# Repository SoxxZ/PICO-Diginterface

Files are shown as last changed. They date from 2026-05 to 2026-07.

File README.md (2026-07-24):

# PICO-Diginterface

An RP2040-based digital interface for amateur radio. Enumerates as a UAC2 sound card and CDC virtual COM port, providing microphone input, PDM speaker output, dual PTT channels, and CAT control passthrough over a single USB connection.

Inspired by [AIOC](https://github.com/skuep/AIOC).

---

## Hardware

The PCB implements full galvanic isolation between the host interface and the radio to eliminate ground loops and RF interference, using PC817 optocouplers and 1:1 600 ohms isolation transformers.

### Pinout

| GPIO | Function | Direction | Notes |
|---|---|---|---|
| 4 | UART1 TX | Output | Inverted, 4800 baud |
| 5 | UART1 RX | Input | Inverted, pull-up enabled |
| 12 | PTT Status LED | Output | Active high; asserted when any PTT channel is active |
| 17 | PDM Data Out | Output (PIO) | PDM bitstream at 1.536 MHz |
| 22 | PTT Channel 1  | Output | Active high |
| 24 | PTT Channel 2  | Output | Active high |
| 25 | Board LED | Output | Blinks USB status |
| 26 | Mic Input | Analog input | ADC channel 0, 12-bit, 48 kHz |

---

## Firmware

### Overview

When connected to a host PC, the firmware presents three USB interfaces:

- **UAC2 Microphone** — 48 kHz, 16-bit mono audio captured via the on-board 12-bit ADC
- **UAC2 Speaker** — 48 kHz, 16-bit mono audio from the host, output as a PDM bitstream via PIO
- **CDC Serial** — Virtual COM port bridged to UART1 for CAT rig control and radio programming

### Features

- **USB Audio (UAC2)** — Full-duplex USB Audio Class 2 interface. Microphone path: 48 kHz, 12-bit ADC, transmitted as 16-bit PCM. Speaker path: 48 kHz / 16-bit PCM from host, output as a 1.536 MHz PDM bitstream via PIO.
- **Push-to-Talk** — Two independent PTT output channels, keyed automatically when the received audio level exceeds a configurable threshold. A hold-off timer keeps the channel open for a defined period after the signal drops.
- **CAT Control Bridge** — Bidirectional CDC serial passthrough to UART1 (inverted, 4800 baud) for rig control and radio programming.

### LED Status

| Blink Interval | State |
|---|---|
| Solid on | Audio streaming |
| 250 ms | Unmounted |
| 1000 ms | Mounted, idle |
| 2500 ms | Not mounted / suspended |

### Building

#### Prerequisites

- [Raspberry Pi Pico SDK](https://github.com/raspberrypi/pico-sdk) v1.5.1 or later
- CMake 3.19+
- ARM GCC toolchain

#### Compiling

```bash
mkdir build && cd build
cmake .. -DPICO_SDK_PATH=/path/to/pico-sdk
make -j$(nproc)
```

Flash the resulting `.uf2` file by holding BOOTSEL while connecting the board, then copying the file to the mass storage device that appears.

## Enjoy the project and 73 de PP2GS!

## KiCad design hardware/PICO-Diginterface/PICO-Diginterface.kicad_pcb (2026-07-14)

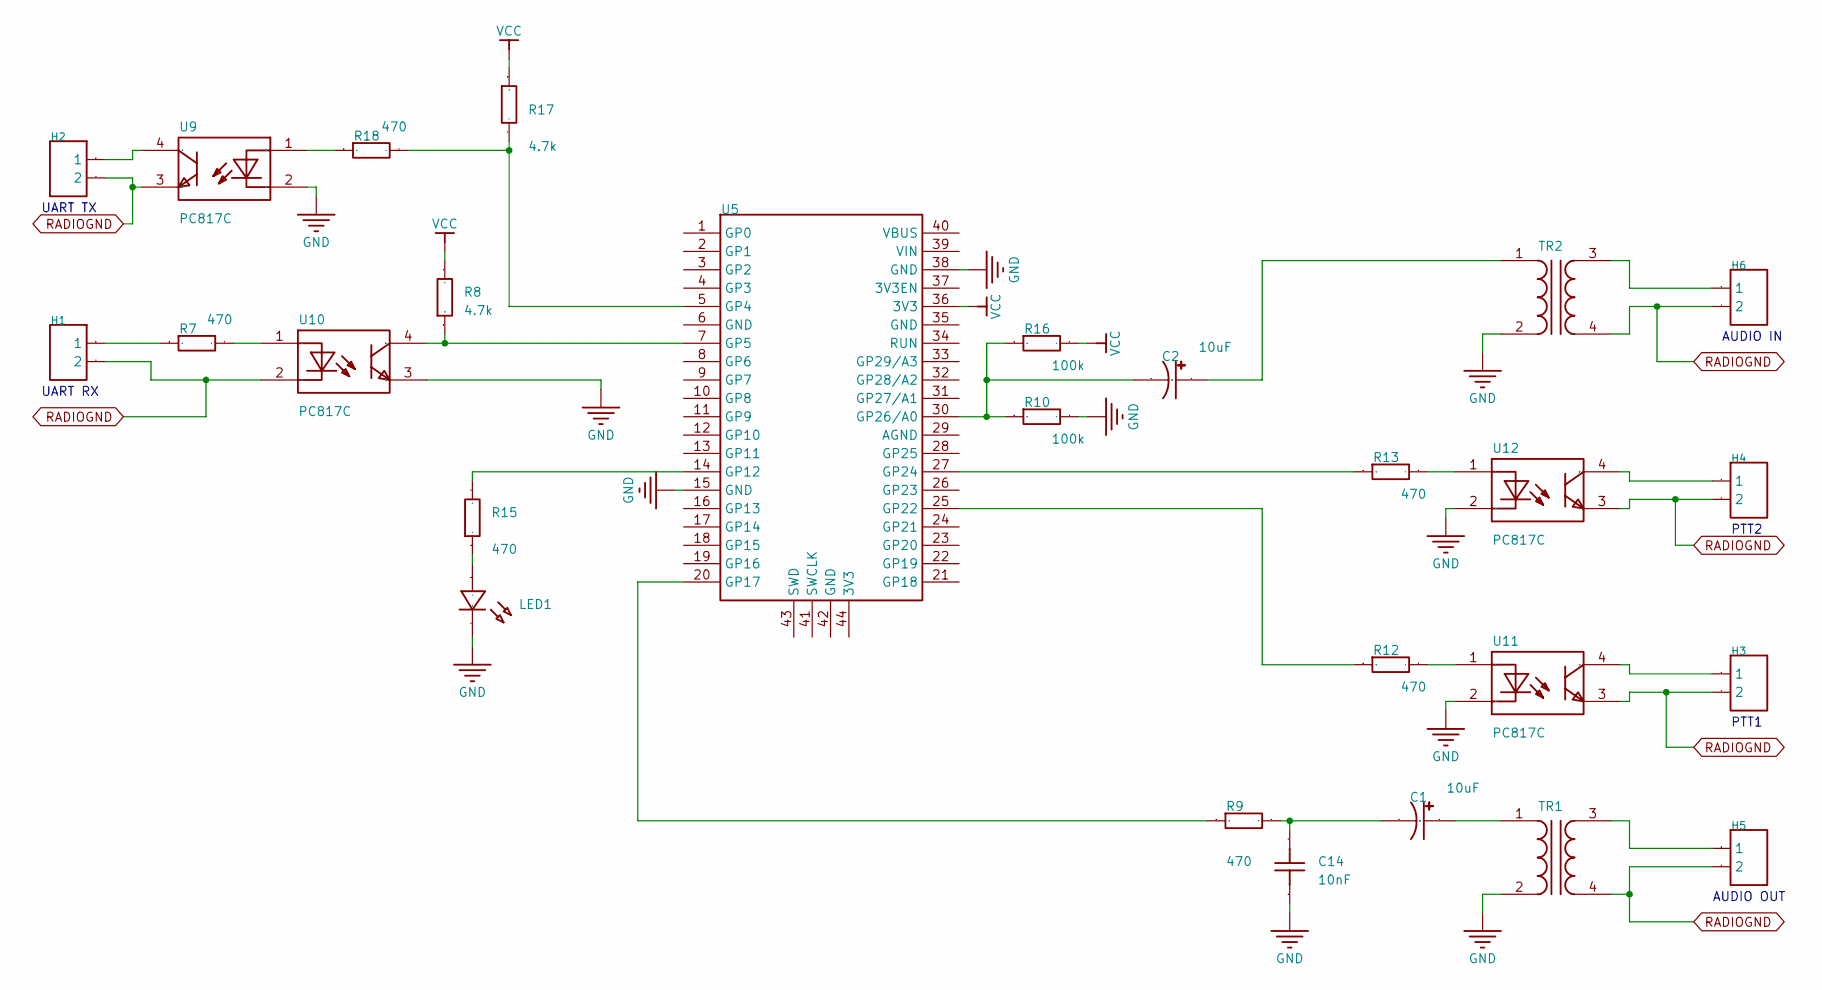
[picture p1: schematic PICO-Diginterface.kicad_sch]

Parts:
C1, C2: 10uF; CAP-TH_BD12.5-P5.00-D0.6-FD; Manufacturer Part ECR1EBK222MLL125025; LCSC Part Name 2200uF ±20% 25V
C14: 10nF; CAP-TH_L5.1-W3.2-P2.54-D0.5; Manufacturer Part C322C103K5R5TA; LCSC Part Name 10nF ±10% 50V
H1, H2, H3, H4, H5, H6: HDR-TH_2P-P2.54-V-F
LED1: LED-TH_BD3.0-P2.54-FD
R7, R9, R12, R13, R15, R18: 470; R0603
R8, R17: 4.7k; R0603
R10, R16: 100k; R0603
TR1, TR2: TRANSFORMER AUDIO 1:1; Manufacturer Part AUDIO TRANSFORMER
U5: PurplePICORP2040TH
U9, U10, U11, U12: PC817C; DIP-4_L4.6-W6.5-P2.54-LS7.6-BL; Manufacturer Part PC817C; LCSC Part Name 4引脚DIP封装光电晶体管光电耦合器

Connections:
$1N291: R7.2, U10.1 (AN)
$1N1419: R8.1, U5.7 (GP5), U10.4 (COL)
$1N1678: H1.1, R7.1
$1N2389: H3.1, U11.4 (COL)
$1N2397: R12.2, U11.1 (AN)
$1N2401: R12.1, U5.25 (GP22)
$1N2767: R13.1, U5.27 (GP24)
$1N2874: R13.2, U12.1 (AN)
$1N2953: C2.2, R10.1, R16.1, U5.30 (GP26/A0)
$1N3686: C2.1, TR2.1
$1N3835: H6.1, TR2.3
$1N3910: R15.2, U5.14 (GP12)
$1N3945: LED1.1 (C), R15.1
$1N4712: H2.1, U9.4 (COL)
$1N4720: R18.1, U9.1 (AN)
$1N4725: R17.2, R18.2, U5.5 (GP4)
$1N4836: H4.1, U12.4 (COL)
$1N5390: C1.2, C14.2, R9.2
$1N5395: C1.1, TR1.1
$1N5400: H5.1, TR1.3
$1N5543: R9.1, U5.20 (GP17)
GND: C14.1, LED1.2 (A), R10.2, TR1.2, TR2.2, U5.15 (GND), U5.38 (GND), U9.2 (CAT), U10.3 (EM), U11.2 (CAT), U12.2 (CAT)
RADIOGND: H1.2, H2.2, H3.2, H4.2, H5.2, H6.2, TR1.4, TR2.4, U9.3 (EM), U10.2 (CAT), U11.3 (EM), U12.3 (EM)
VCC: R8.2, R16.2, R17.1, U5.36 (3V3)

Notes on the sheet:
PTT2
PTT1
UART TX
AUDIO IN
AUDIO OUT
UART RX

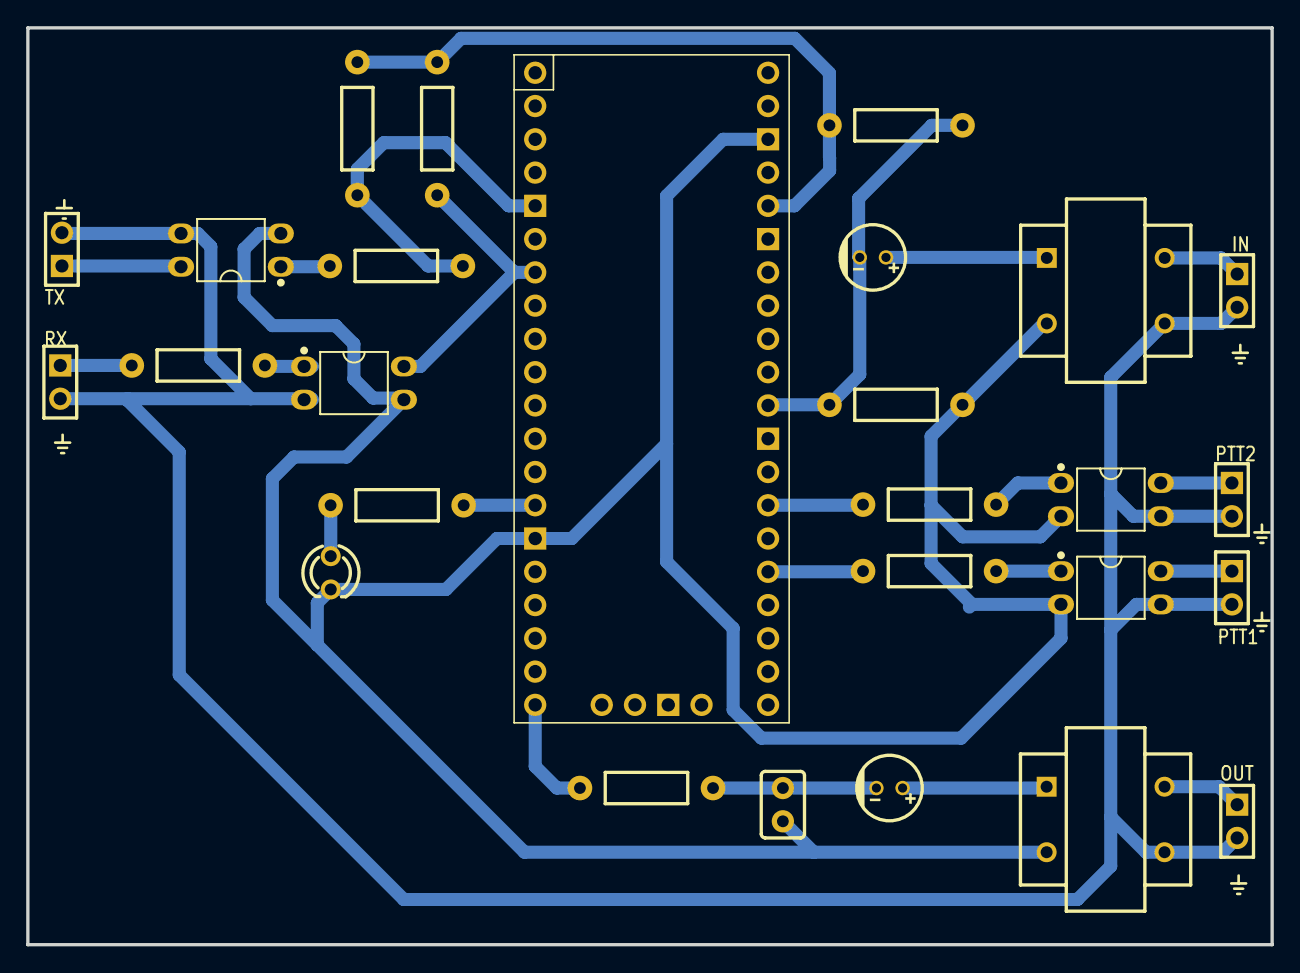
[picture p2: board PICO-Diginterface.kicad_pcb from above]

Board: 2 copper layers, 95.0 x 70.0 mm, 27 parts (0 on the bottom side), 24 nets.

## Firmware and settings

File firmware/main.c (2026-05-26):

#include <stdio.h>
#include <string.h>
#include "pico/stdlib.h"
#include "hardware/uart.h"
#include "bsp/board_api.h"
#include "tusb.h"
#include "usb_descriptors.h"
#include "audio_pdm_output.h"
#include "adc_input.h"
#include "ptt.h"

static const uint32_t sample_rates[] = {48000};
static uint32_t current_sample_rate = 48000;

enum {
    VOLUME_CTRL_0_DB = 0,
    VOLUME_CTRL_50_DB = 12800,
};

static uint32_t blink_interval_ms = 250;

static int8_t mute[2];
static int16_t volume[2];

static int16_t spk_buf[48];
static volatile int spk_data_size = 0;

static void audio_task(void);
static void led_blinking_task(void);
static void cdc_task(void);

int main(void) {
    board_init();
    stdio_init_all();

    audio_pdm_output_init(48000);
    adc_input_init();
    ptt_init();

    uart_init(uart1, 4800);
    gpio_set_function(4, GPIO_FUNC_UART);
    gpio_set_function(5, GPIO_FUNC_UART);
    gpio_set_outover(4, GPIO_OVERRIDE_INVERT);
    gpio_set_inover(5, GPIO_OVERRIDE_INVERT);
    gpio_pull_up(5);
    uart_set_format(uart1, 8, 2, UART_PARITY_NONE);

    tusb_init();

    while (1) {
        tud_task();
        cdc_task();
        audio_task();
        led_blinking_task();
    }
}

void tud_mount_cb(void) {
    blink_interval_ms = 1000;
}

void tud_umount_cb(void) {
    blink_interval_ms = 250;
}

void tud_suspend_cb(bool remote_wakeup_en) {
    (void)remote_wakeup_en;
    blink_interval_ms = 2500;
}

void tud_resume_cb(void) {
    blink_interval_ms = tud_mounted() ? 1000 : 250;
}

static bool tud_audio_clock_get_request(uint8_t rhport, audio_control_request_t const *request) {
    if (request->bEntityID != UAC2_ENTITY_CLOCK) return false;

    if (request->bControlSelector == AUDIO_CS_CTRL_SAM_FREQ) {
        if (request->bRequest == AUDIO_CS_REQ_CUR) {
            audio_control_cur_4_t curf = { (int32_t)tu_htole32(current_sample_rate) };
            return tud_audio_buffer_and_schedule_control_xfer(rhport,
                (tusb_control_request_t const *)request, &curf, sizeof(curf));
        } else if (request->bRequest == AUDIO_CS_REQ_RANGE) {
            audio_control_range_4_n_t(1) rangef = {
                .wNumSubRanges = tu_htole16(1),
                .subrange[0] = { .bMin = 48000, .bMax = 48000, .bRes = 0 }
            };
            return tud_audio_buffer_and_schedule_control_xfer(rhport,
                (tusb_control_request_t const *)request, &rangef, sizeof(rangef));
        }
    } else if (request->bControlSelector == AUDIO_CS_CTRL_CLK_VALID &&
               request->bRequest == AUDIO_CS_REQ_CUR) {
        audio_control_cur_1_t cur_valid = { .bCur = 1 };
        return tud_audio_buffer_and_schedule_control_xfer(rhport,
            (tusb_control_request_t const *)request, &cur_valid, sizeof(cur_valid));
    }
    return false;
}

static bool tud_audio_clock_set_request(uint8_t rhport, audio_control_request_t const *request, uint8_t const *buf) {
    (void)rhport;
    if (request->bEntityID != UAC2_ENTITY_CLOCK) return false;
    if (request->bControlSelector == AUDIO_CS_CTRL_SAM_FREQ &&
        request->bRequest == AUDIO_CS_REQ_CUR) {
        current_sample_rate = (uint32_t)((audio_control_cur_4_t const *)buf)->bCur;
        return true;
    }
    return false;
}

static bool tud_audio_feature_unit_get_request(uint8_t rhport, audio_control_request_t const *request) {
    if (request->bEntityID != UAC2_ENTITY_SPK_FEATURE_UNIT) return false;

    if (request->bControlSelector == AUDIO_FU_CTRL_MUTE && request->bRequest == AUDIO_CS_REQ_CUR) {
        audio_control_cur_1_t mute1 = { .bCur = mute[request->bChannelNumber] };
        return tud_audio_buffer_and_schedule_control_xfer(rhport,
            (tusb_control_request_t const *)request, &mute1, sizeof(mute1));
    } else if (request->bControlSelector == AUDIO_FU_CTRL_VOLUME) {
        if (request->bRequest == AUDIO_CS_REQ_CUR) {
            audio_control_cur_2_t cur_vol = { .bCur = tu_htole16(volume[request->bChannelNumber]) };
            return tud_audio_buffer_and_schedule_control_xfer(rhport,
                (tusb_control_request_t const *)request, &cur_vol, sizeof(cur_vol));
        } else if (request->bRequest == AUDIO_CS_REQ_RANGE) {
            audio_control_range_2_n_t(1) range_vol = {
                .wNumSubRanges = tu_htole16(1),
                .subrange[0] = { .bMin = tu_htole16(-VOLUME_CTRL_50_DB),
                                 .bMax = tu_htole16(VOLUME_CTRL_0_DB),
                                 .bRes = tu_htole16(256) }
            };
            return tud_audio_buffer_and_schedule_control_xfer(rhport,
                (tusb_control_request_t const *)request, &range_vol, sizeof(range_vol));
        }
    }
    return false;
}

static bool tud_audio_feature_unit_set_request(uint8_t rhport, audio_control_request_t const *request, uint8_t const *buf) {
    (void)rhport;
    if (request->bEntityID != UAC2_ENTITY_SPK_FEATURE_UNIT) return false;
    if (request->bRequest != AUDIO_CS_REQ_CUR) return false;

    if (request->bControlSelector == AUDIO_FU_CTRL_MUTE) {
        mute[request->bChannelNumber] = ((audio_control_cur_1_t const *)buf)->bCur;
        return true;
    } else if (request->bControlSelector == AUDIO_FU_CTRL_VOLUME) {
        volume[request->bChannelNumber] = ((audio_control_cur_2_t const *)buf)->bCur;
        return true;
    }
    return false;
}

bool tud_audio_get_req_entity_cb(uint8_t rhport, tusb_control_request_t const *p_request) {
    audio_control_request_t const *request = (audio_control_request_t const *)p_request;

    if (request->bEntityID == UAC2_ENTITY_CLOCK)
        return tud_audio_clock_get_request(rhport, request);
    if (request->bEntityID == UAC2_ENTITY_SPK_FEATURE_UNIT)
        return tud_audio_feature_unit_get_request(rhport, request);
    return false;
}

bool tud_audio_set_req_entity_cb(uint8_t rhport, tusb_control_request_t const *p_request, uint8_t *buf) {
    audio_control_request_t const *request = (audio_control_request_t const *)p_request;

    if (request->bEntityID == UAC2_ENTITY_SPK_FEATURE_UNIT)
        return tud_audio_feature_unit_set_request(rhport, request, buf);
    if (request->bEntityID == UAC2_ENTITY_CLOCK)
        return tud_audio_clock_set_request(rhport, request, buf);
    return false;
}

bool tud_audio_set_itf_close_EP_cb(uint8_t rhport, tusb_control_request_t const *p_request) {
    (void)rhport;
    uint8_t const itf = tu_u16_low(tu_le16toh(p_request->wIndex));
    if (ITF_NUM_AUDIO_STREAMING_SPK == itf)
        blink_interval_ms = 1000;
    return true;
}

bool tud_audio_set_itf_cb(uint8_t rhport, tusb_control_request_t const *p_request) {
    (void)rhport;
    uint8_t const itf = tu_u16_low(tu_le16toh(p_request->wIndex));
    uint8_t const alt = tu_u16_low(tu_le16toh(p_request->wValue));

    if (ITF_NUM_AUDIO_STREAMING_SPK == itf && alt != 0)
        blink_interval_ms = 0;

    spk_data_size = 0;
    return true;
}

bool tud_audio_rx_done_pre_read_cb(uint8_t rhport, uint16_t n_bytes_received,
                                   uint8_t func_id, uint8_t ep_out, uint8_t cur_alt_setting) {
    (void)rhport;
    (void)func_id;
    (void)ep_out;
    (void)cur_alt_setting;

    spk_data_size = tud_audio_read(spk_buf, n_bytes_received);
    return true;
}

bool tud_audio_tx_done_pre_load_cb(uint8_t rhport, uint8_t func_id,
                                   uint8_t ep_in, uint8_t cur_alt_setting) {
    (void)rhport;
    (void)func_id;
    (void)ep_in;
    (void)cur_alt_setting;
    return true;
}

void audio_task(void) {
    if (spk_data_size) {
        int16_t *src = spk_buf;
        int count = spk_data_size / 2;
        uint32_t now = time_us_32();
        for (int i = 0; i < count; i++) {
            audio_pdm_output_write(src[i]);
            ptt_process_sample(src[i], now);
        }
        spk_data_size = 0;
    }
    while (audio_pdm_output_is_ready())
        audio_pdm_output_write(0);
}

static void cdc_task(void) {
    if (tud_cdc_connected()) {
        uint8_t buf[64];
        uint32_t count = tud_cdc_read(buf, sizeof(buf));
        if (count > 0) {
            uart_write_blocking(uart1, buf, count);
        }

        count = 0;
        while (uart_is_readable(uart1) && count < sizeof(buf)) {
            buf[count++] = uart_getc(uart1);
        }
        if (count > 0) {
            tud_cdc_write(buf, count);
            tud_cdc_write_flush();
        }
    }
}

void tud_cdc_line_coding_cb(uint8_t itf, cdc_line_coding_t const *p_line_coding) {
    (void)itf;
    (void)p_line_coding;
}

void tud_cdc_send_break_cb(uint8_t itf, uint16_t duration_ms) {
    (void)itf;
    (void)duration_ms;
}

void led_blinking_task(void) {
    if (blink_interval_ms == 0) {
        board_led_write(true);
        return;
    }
    static uint32_t start_ms = 0;
    static bool led_state = false;

    if (board_millis() - start_ms < blink_interval_ms) return;
    start_ms += blink_interval_ms;

    board_led_write(led_state);
    led_state = !led_state;
}

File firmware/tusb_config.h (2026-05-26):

#ifndef _TUSB_CONFIG_H_
#define _TUSB_CONFIG_H_

#ifdef __cplusplus
extern "C" {
#endif

#include "usb_descriptors.h"

#ifndef BOARD_TUD_RHPORT
#define BOARD_TUD_RHPORT      0
#endif

#ifndef BOARD_TUD_MAX_SPEED
#define BOARD_TUD_MAX_SPEED   OPT_MODE_DEFAULT_SPEED
#endif

#ifndef CFG_TUSB_MCU
#error CFG_TUSB_MCU must be defined
#endif

#ifndef CFG_TUSB_OS
#define CFG_TUSB_OS           OPT_OS_NONE
#endif

#ifndef CFG_TUSB_DEBUG
#define CFG_TUSB_DEBUG        2
#endif

#define CFG_TUSB_RHPORT0_MODE OPT_MODE_DEVICE

#define CFG_TUD_ENABLED       1

#define CFG_TUD_MAX_SPEED     BOARD_TUD_MAX_SPEED

#ifndef CFG_TUSB_MEM_SECTION
#define CFG_TUSB_MEM_SECTION
#endif

#ifndef CFG_TUSB_MEM_ALIGN
#define CFG_TUSB_MEM_ALIGN        __attribute__ ((aligned(4)))
#endif

#ifndef CFG_TUD_ENDPOINT0_SIZE
#define CFG_TUD_ENDPOINT0_SIZE    64
#endif

#define CFG_TUD_CDC               1
#define CFG_TUD_MSC               0
#define CFG_TUD_HID               0
#define CFG_TUD_MIDI              0
#define CFG_TUD_AUDIO             1
#define CFG_TUD_VENDOR            0

#define CFG_TUD_CDC_RX_BUFSIZE   64
#define CFG_TUD_CDC_TX_BUFSIZE   64

#define CFG_TUD_AUDIO_ENABLE_INTERRUPT_EP                    0

#define CFG_TUD_AUDIO_FUNC_1_DESC_LEN                        TUD_AUDIO_HEADSET_MONO_DESC_LEN

#define CFG_TUD_AUDIO_FUNC_1_N_FORMATS                       1

#define CFG_TUD_AUDIO_FUNC_1_MAX_SAMPLE_RATE                 48000
#define CFG_TUD_AUDIO_FUNC_1_N_CHANNELS_TX                   1
#define CFG_TUD_AUDIO_FUNC_1_N_CHANNELS_RX                   1

#define CFG_TUD_AUDIO_FUNC_1_FORMAT_1_N_BYTES_PER_SAMPLE_TX  2
#define CFG_TUD_AUDIO_FUNC_1_FORMAT_1_RESOLUTION_TX          16
#define CFG_TUD_AUDIO_FUNC_1_FORMAT_1_N_BYTES_PER_SAMPLE_RX  2
#define CFG_TUD_AUDIO_FUNC_1_FORMAT_1_RESOLUTION_RX          16

#define CFG_TUD_AUDIO_ENABLE_EP_IN                           1

#define CFG_TUD_AUDIO_FUNC_1_FORMAT_1_EP_SZ_IN               TUD_AUDIO_EP_SIZE(CFG_TUD_AUDIO_FUNC_1_MAX_SAMPLE_RATE, CFG_TUD_AUDIO_FUNC_1_FORMAT_1_N_BYTES_PER_SAMPLE_TX, CFG_TUD_AUDIO_FUNC_1_N_CHANNELS_TX)

#define CFG_TUD_AUDIO_FUNC_1_EP_IN_SW_BUF_SZ                 CFG_TUD_AUDIO_FUNC_1_FORMAT_1_EP_SZ_IN * 4
#define CFG_TUD_AUDIO_FUNC_1_EP_IN_SZ_MAX                    CFG_TUD_AUDIO_FUNC_1_FORMAT_1_EP_SZ_IN

#define CFG_TUD_AUDIO_ENABLE_EP_OUT                           1

#define CFG_TUD_AUDIO_FUNC_1_FORMAT_1_EP_SZ_OUT               TUD_AUDIO_EP_SIZE(CFG_TUD_AUDIO_FUNC_1_MAX_SAMPLE_RATE, CFG_TUD_AUDIO_FUNC_1_FORMAT_1_N_BYTES_PER_SAMPLE_RX, CFG_TUD_AUDIO_FUNC_1_N_CHANNELS_RX)

#define CFG_TUD_AUDIO_FUNC_1_EP_OUT_SW_BUF_SZ                CFG_TUD_AUDIO_FUNC_1_FORMAT_1_EP_SZ_OUT * 2
#define CFG_TUD_AUDIO_FUNC_1_EP_OUT_SZ_MAX                   CFG_TUD_AUDIO_FUNC_1_FORMAT_1_EP_SZ_OUT

#define CFG_TUD_AUDIO_FUNC_1_N_AS_INT                        2

#define CFG_TUD_AUDIO_FUNC_1_CTRL_BUF_SZ                     64

#ifdef __cplusplus
}
#endif

#endif

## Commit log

2026-05-26 changed from easyeda to kicad
    [Drill_PTH_Through.DRL, Gerber_BoardOutlineLayer.GKO, Gerber_BottomLayer.GBL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]
2026-05-26 fix CI: bump Pico SDK from 1.5.1 to 2.2.0
    SDK 1.5.1 bundles an old TinyUSB that lacks bsp/board_api.h.
    SDK 2.2.0 has it, matching the local development environment.
2026-07-14 hardware change: common grounds on radio side
    [PICO-Diginterface.kicad_pcb, PICO-Diginterface.kicad_sch]
2026-07-24 changing pin of audio output to match hardware
